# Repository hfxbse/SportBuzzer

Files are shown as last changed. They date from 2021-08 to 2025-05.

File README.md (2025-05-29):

# SportBuzzer
Wireless time measurement with two buzzer buttons, which also work as standalone.

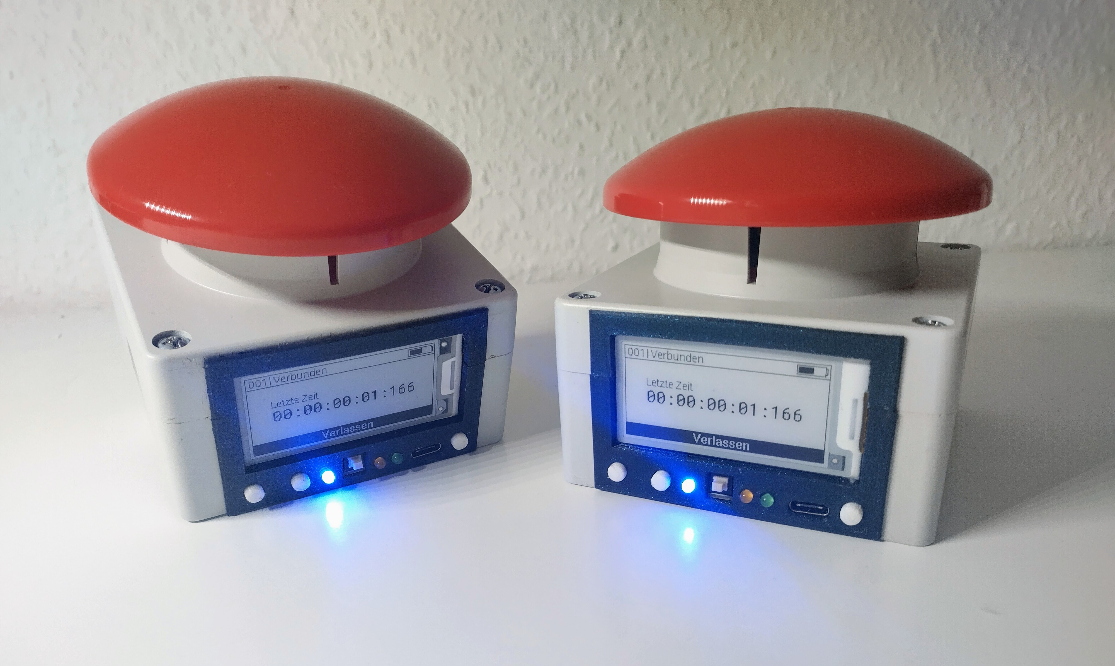
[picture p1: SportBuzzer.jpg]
Two SportBuzzer paired showing the same stopwatch time


## Usage
The GUI is controlled by the three buttons, called previous, next, and confirm. Generally speaking,
while navigating you use the previous button to go to the previous element, the next button to go to the
next element, and press the confirm button, to leave or enter a menu.

To change a value, you first need to navigate to the corresponding element. Then you press the confirm
button to start changing the value. Use the previous button to lower the value and use the next button
to increase it. When done editing the value, press the confirm button again to confirm your input.

While being in either the stopwatch or timer mode, pressing the buzzer button will start the time, and pressing
the buzzer button again will stop it. You can also cancel out by pressing the confirm button on the cancel element.
**After canceling no result is shown.**

When in the same wireless channel and same mode, pressing either of the buzzer buttons will stop the time.

Detailed information about the usage and limits can be found in the
[wiki](https://github.com/StuBITtv/SportBuzzer/wiki).

## Hardware

The design is based around the
[STM32L151CBU6 microcontroller](https://www.st.com/en/microcontrollers-microprocessors/stm32l151cb.html), which drives
an HC12 long-range wireless communication module and a
[Waveshare 2.13-inch black and white e-ink display](https://www.waveshare.com/2.13inch-e-Paper-HAT.htm). The board is
powered via a 1000mAh LiPo battery which is charged via USB-C. The data lines of the USB-C port are connected to the
MCU to provide expandability as well as an exposed additional UART connection on the PCB itself.

**Even though this project uses an HC12 module, I highly recommend replacing it.** Not only is it practically impossible
to find genuine modules which can deliver on the promised range, but more importantly, requires the used frequency of
433 MHz a license in large parts of the world. A promising alternative could be the
[RYLR998 LoRa module by REYAX](https://reyax.com/products/rylr998/). It operates in a license-free frequency range,
should achieve an even higher range, and has a small size. As it gets also controlled via AT commands like the HC12, the
changes required should be small.

JTAG and UART with buttons to select the boot mode are also exposed for uploading and debugging firmware.

The base of the casing is [this emergency off buzzer](https://bit.ly/3QsfA5K), all other parts are 3D-printed. One of
the wider sides is then cut open to place the front panel, which also secures the display. The other components are on a
mounting system, which is screwed to the bottom of the buzzer.

Due to the limited size of the chosen casing, a custom PCB is used. The schematics are created with
[EasyEDA](https://easyeda.com/), as their integration with [LCSC Electronics](https://www.lcsc.com/) made the design
and ordering process a lot simpler for me. As this is a cloud-based solution, you can open the
[schematics](https://oshwlab.com/StuBIT/sportbuzzer) directly.

Schematics

The production files are also directly included in this repository, nevertheless.

## Code

This project uses an [Arduino CMake toolchain](https://github.com/a9183756-gh/Arduino-CMake-Toolchain/),
but it is still possible to compile it within the [Arduino IDE](https://www.arduino.cc/en/Main/Software).
The only limitations are as follows:

* The `SportBuzzer.ino` file needs to be a file without any code in it to keep it compatible with both the
  Arduino IDE and the CMake toolchain. The only purpose of this file is to make it possible to open the
  project in the Arduino IDE.
* Due to the project size, it is necessary to split the project into multiple source files, which are organized in
  directories. The starting point of those directories needs to be `src/`, so the Arduino IDE picks it up. Still, the
  Arduino IDE won't show the directories and the containing files in the Editor.

The basic concepts of the code are as follows:

* Abstract the hardware as much as needed, so you are able to change it without needing to change stuff all over
  the code base.
* The main loop (`void loop()` to be more specific) handles background tasks. Background tasks include checking the
  battery level and the connection status. The main loop updates the foreground task (called `GUITask`) also,
  providing information about the hardware state, which it has already queried. To keep the displayed device state up
  to date, it may redraw the GUI arbitrarily.
* A GUITask handles everything related to its options, and time measurements. When done updating, it returns
  itself to keep alive, or a new GUITask to exit. After exiting, its state gets destroyed.
* To get accurate times without being limited by the refresh rate of the display, the buzzer is handled completely via
  interrupts. Implementations of GUITask rely on the time when the buzzer was pressed to detect if it was pressed.

Full documentation of the code can be found in the [wiki](https://github.com/StuBITtv/SportBuzzer/wiki).

Support from the Arduino IDE for the STM32-based microcontroller is added via the
[stm32duino](https://github.com/stm32duino/Arduino_Core_STM32) project. The correct settings for the custom PCB are
as follows:

* Board: "Generic STM32L1 series"
* Board part number: "GenericL151CBUx"

Remember to also choose the appropriate upload method.

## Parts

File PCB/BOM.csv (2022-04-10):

ID | Name | Designator | Footprint | Quantity | Manufacturer Part | Manufacturer | Supplier | Supplier Part
1 | 340kΩ | R11,R19,R21 | R0603 | 3 | 0603WAF3403T5E | UniOhm | LCSC | C23143
2 | SOFTWARE | BUZZER2 | BUZ-TH_BD12.0-P6.50-D0.6-FD | 1 | GMC1205YA-16R2048 | INGHAi | LCSC | C252915
3 | 22uF | C13 | C0603 | 1 | CL10A226MQ8NRNC | SAMSUNG | LCSC | C59461
4 | HC12 | H3 | HDR-TH_5P-P2.54-V-M | 1 | MTP125-1105S1 | MINTRON | LCSC | C358687
5 | DISPLAY | H4 | HDR-TH_8P-P2.54-V-M | 1 | Z-211-0811-0021-001 | Nextronics Engineering | LCSC | C190820
6 | BUZZER+ | P1 | HDR-TH_1P-P2.54-V-M | 1 | Header-Male-2.54_1x1 | ReliaPro | LCSC | C81276
7 | BUZZER- | P2 | HDR-TH_1P-P2.54-V-M | 1 | Header-Male-2.54_1x1 | ReliaPro | LCSC | C81276
8 | TYPE-C-31-M-14 | USBC1 | USB-C-SMD_12P-P0.50-H-F_TYPE-C-31-M-14 | 1 | TYPE-C-31-M-14 | Rectangular Connectors - Contacts | LCSC | C223907
9 | 200kΩ | R17,R20 | R0603 | 2 | 0603WAF2003T5E | UniOhm | LCSC | C25811
10 | 10uF | C9,C1,C2,C3,C4,C5,C6,C11 | C0402 | 8 | CL05A106MQ5NUNC | SAMSUNG | LCSC | C15525
11 | 1.5nF | C10 | C0402 | 1 | CL05B152KB5NNNC | SAMSUNG | LCSC | C23967
12 | 10uH | L1 | L0603 | 1 | SDFL1608S100KTF | Sunlord | LCSC | C1035
13 | 60.4kΩ | R10 | R0603 | 1 | 0603WAF6042T5E | UniOhm | LCSC | C23089
14 | 1.5kΩ | R18 | R0603 | 1 | 0603WAJ0152T5E | UniOhm | LCSC | C25989
15 | TX4401 | U3 | SOP-8_L4.9-W3.9-P1.27-LS6.0-BL-EP | 1 | TX4401 | XDS | LCSC | C448642
16 | JTAG | H1 | HDR-TH_4P-P2.54-H-M-W10.4 | 1 | 2.54-1*4P反弯排针 | BOOMELE(博穆精密) | LCSC | C91552
17 | 10K | R12,R16,R3,R7,R8,R9 | R0603 | 6 | 0603WAF1002T5E | UniOhm | LCSC | C25804
18 | 100 | R13,R4 | R0603 | 2 | 0603WAF1000T5E | UniOhm | LCSC | C22775
19 | 2.1K | R14 | R0603 | 1 | 0603WAF2101T5E | UniOhm | LCSC | C22902
20 | 25.5K | R15 | R0603 | 1 | 0603WAF2552T5E | UniOhm | LCSC | C22920
21 | Battery | H6 | CONN-TH_S2B-PH-K-S-LF-SN | 1 | S2B-PH-K-S(LF)(SN) | JST Sales America | LCSC | C173752
22 | 1TS001G-1600-1700 | BOOT0,RESET | SW-SMD_4P-L5.1-W5.1-P3.70-LS6.5-TL-2 | 2 | 1TS001G-1600-1700 | HYP | LCSC | C318802
23 | HARDWARE | BUZZER1 | BUZ-TH_BD9.0-P4.00-D0.6-FD | 1 | GMC0942YB-16R2700 | INGHAi | LCSC | C252926
24 | 10nF | C12,C7,C8 | C0402 | 3 | CL05B103KB5NNNC | SAMSUNG | LCSC | C15195
25 | ORANGE | CHRG | LED-TH_BD3.0-P2.54-FD | 1 | TJ-L3FYTXHAMCGLFLC0A-A5 | TOGIALED | LCSC | C330758
26 | BLUE | POWER | LED-TH_BD3.0-P2.54-FD | 1 | TJ-L3FYTGCBMCGSFLC6B-A5 | TOGIALED | LCSC | C330760
27 | TC-1109DE-C-D | CONF,NEXT,PREV | SW-TH_TC-1109DE-C-D | 3 | TC-1109DE-C-D | XKB Enterprise | LCSC | C400333
28 | B5819W_C8598 | D1,D2,D3 | SOD-123_L2.8-W1.8-LS3.7-RD | 3 | B5819W | CJ | LCSC | C8598
29 | GREEN | DONE | LED-TH_BD3.9-P2.54-L-RD | 1 | TJ-L3FYTGCGMCGLFLC2G-A5 | TOGIALED | LCSC | C331056
30 | UART1 | H2 | HDR-TH_2P-P2.54-H-M-W7.3 | 1 | 1125-1102G0R138C002 | Wcon | LCSC | C721441
31 | USART2 | H5 | HDR-TH_4P-P2.54-V-M-1 | 1 | MTP125-1104S1 | MINTRON | LCSC | C358686
32 | SI2301CDS-T1-GE3 | Q1,Q2,Q3,Q4 | SOT-23-3_L3.0-W1.7-P0.95-LS2.9-BR | 4 | SI2301CDS-T1-GE3 | VISHAY | LCSC | C10487
33 | 2K | R1 | R0603 | 1 | 0603WAF2001T5E | UniOhm | LCSC | C22975
34 | 1K | R2 | R0603 | 1 | 0603WAF1001T5E | UniOhm | LCSC | C21190
35 | 5.1K | R5,R6 | R0603 | 2 | 0603WAF5101T5E | UniOhm | LCSC | C23186
36 | XKB5858-Z-C | SW1 | SW-TH_XKB5858-Z-C | 1 | XKB5858-Z-C | XKB Enterprise | LCSC | C318865
37 | LP4074B5F | U1 | TSOT-23-5_L2.9-W1.6-P0.95-LS2.8-BL | 1 | LP4074B5F | LOWPOWER | LCSC | C517037
38 | XB3301AJ | U2 | SOT-23-3_L2.9-W1.6-P1.90-LS2.8-BR | 1 | XB3301AJ | xysemi(赛芯微) | LCSC | C2760004
39 | STM32L151CBU6 | U4 | UFQFPN-48_L7.0-W7.0-P0.50-BL-EP | 1 | STM32L151CBU6 | STMicroelectronics | LCSC | C465975
40 | NE555D_C596355 | U5 | SOP-8_L4.9-W3.9-P1.27-LS6.0-BL | 1 | NE555D | HTC Korea TAEJIN Tech | LCSC | C596355

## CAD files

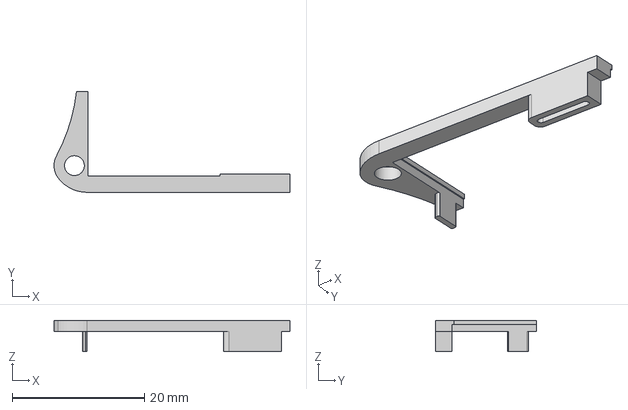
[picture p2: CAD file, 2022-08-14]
casing/STEP/antenna mount.step
35.7 x 15.2 x 4.70 mm

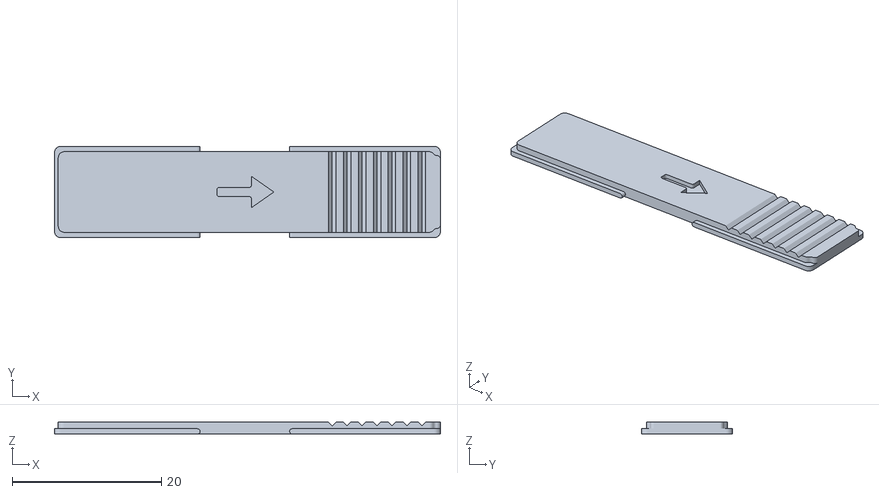
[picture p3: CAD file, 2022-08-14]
casing/STL/battery enclosure lit.stl
51.7 x 12.2 x 1.60

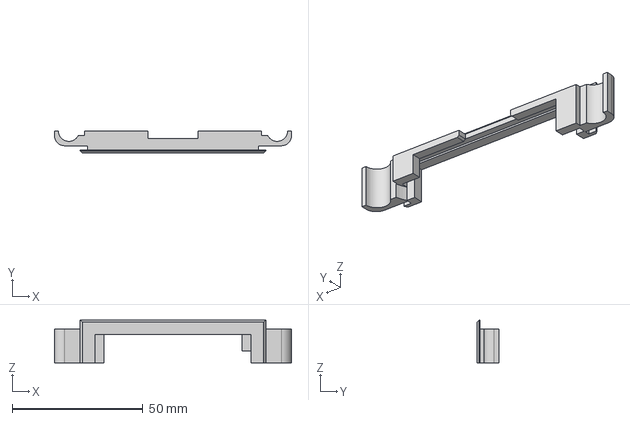
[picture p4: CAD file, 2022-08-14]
casing/STEP/panelling top.step
90.8 x 8.50 x 16.4 mm

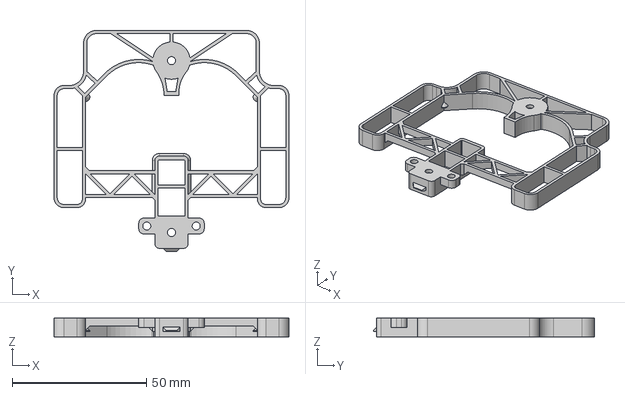
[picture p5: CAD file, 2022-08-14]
casing/STEP/pcb mount.step
87.5 x 82.3 x 7.00 mm

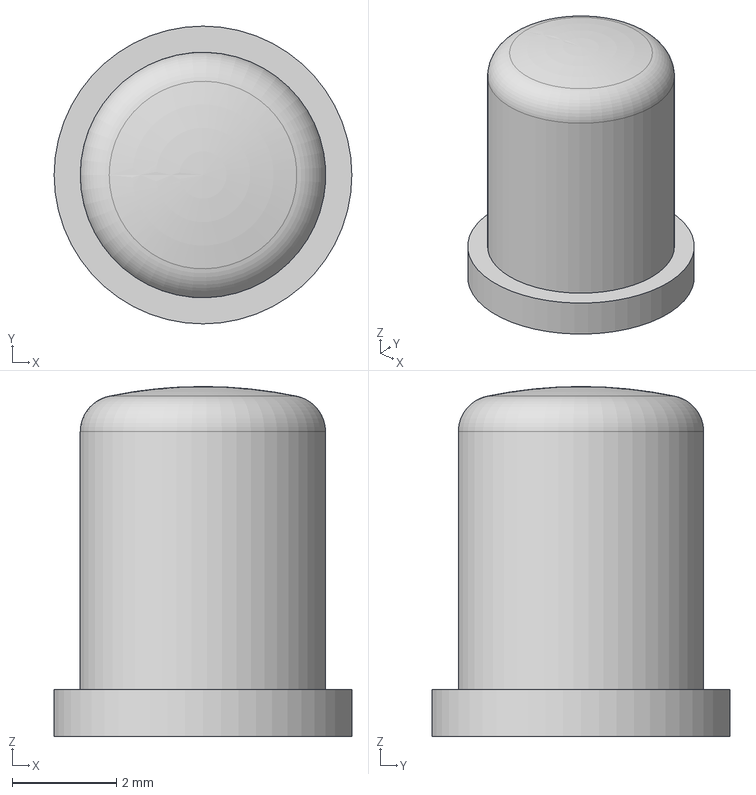
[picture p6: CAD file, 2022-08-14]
casing/STEP/button.step
5.70 x 5.70 x 6.70 mm

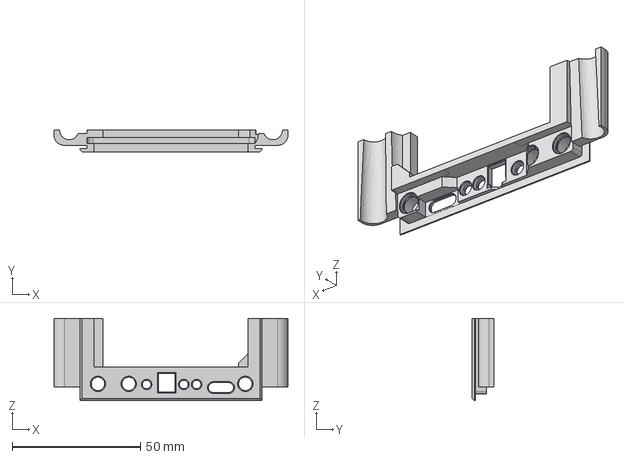
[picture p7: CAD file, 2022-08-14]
casing/STEP/panelling lower.step
91.3 x 8.40 x 32.0 mm

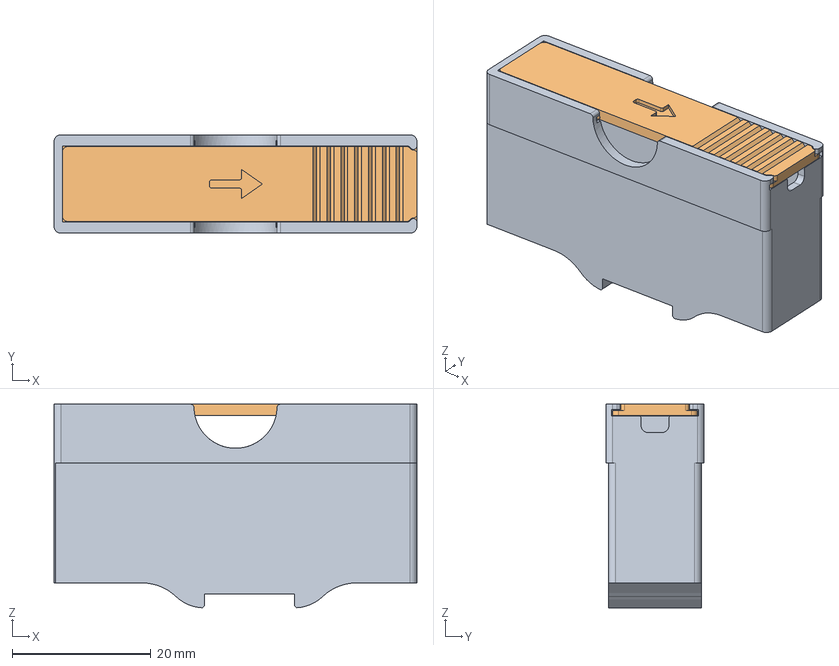
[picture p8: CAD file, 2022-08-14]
casing/STEP/battery enclosure.step
52.4 x 14.2 x 29.4 mm

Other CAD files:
casing/STL/antenna mount.stl
casing/STL/battery enclosure.stl
casing/STL/button.stl
casing/STL/panelling lower.stl
casing/STL/panelling top.stl
casing/STL/pcb mount.stl
casing/antenna mount.f3d
casing/batterie enclosure.f3d
casing/button.f3d
casing/panelling lower.f3d
casing/panelling top.f3d
casing/pcb mount.f3d

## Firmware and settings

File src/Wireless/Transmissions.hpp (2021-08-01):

//
// Created by stubit on 4/25/20.
//

#ifndef SPORTBUZZER_TRANSMISSIONS_HPP
#define SPORTBUZZER_TRANSMISSIONS_HPP


#include <Arduino.h>
#include "../HardwareInterfaces/HC12.hpp"

enum Signal {
    undefined = 0,
    ping = 1,
    pong = 2,
    cancel_stopwatch = 3,
    cancel_timer = 4,
    duration_stopwatch = 5,
    duration_timer = 6,
    limit = 7,
    stopwatch = 8,
    timer = 9,
};

enum TransmissionStatus {
    unfinished = 1,
    finished = 0,
    timeout = -1,
};

class Transmissions {
public:
    explicit Transmissions(HC12 &module);

    void poll();

    bool sendPing(unsigned long timeout);

    TransmissionStatus getPingStatus() const;

    unsigned long getPingResponseTime();

    unsigned long getPingTime() const;

    unsigned long popReceivedPing();

    void sendPingResponse() const;

    void waitOnPing();

    void sendStopwatchSignal() const;

    unsigned long getStopwatchSignalTime() const;

    void sendTimerSignal() const;

    unsigned long getTimerSignalTime() const;

    unsigned long transmissionTimeout = 5000;

    TransmissionStatus getDurationTransmissionStatus() const;

    unsigned long getTransmittedDuration() const;

    void sendDuration(unsigned long duration, bool stopwatch) const;

    byte getDurationNumber() const;

    Signal getDurationSignal() const;

    TransmissionStatus getLimitTransmissionStatus() const;

    long getTransmittedLimit() const;

    void sendLimit(long limit) const;

    byte getLimitNumber() const;

    void sendCancelSignal(bool stopwatch) const;

    byte getCancelNumber() const;

    Signal getCancelSignal() const;

private:
    // related to module
    HC12 &module;

    // related to ping signals
    unsigned long pingStart = 0, pingResponseTime = 0, receivedPingCount = 0, pingTimeout = 0;
    TransmissionStatus pingStatus = finished;

    // related to stopwatch signal
    unsigned long stopwatchTime = 0;

    // related to timer signal
    unsigned long timerTime = 0;

    // related to cancel signal
    byte receivedCancelCount = 0;
    Signal cancelSignal = undefined;

    // related to duration transmission
    TransmissionStatus durationTransmissionStatus = finished;
    byte transmittedDurationBytes = 0, receivedDurationCount = 0;
    unsigned long transmittedDuration = 0, durationTransmissionStart = 0;
    Signal timeSignal = Signal::undefined;

    // related to limit transmission
    TransmissionStatus limitTransmissionStatus = finished;
    byte transmittedLimitBytes = 0, receivedLimitCount = 0;
    long transmittedLimit = 0;
    unsigned long limitTransmissionStart = 0;

    template<typename T>
    T writeData(T value, byte &transmittedByteCount, TransmissionStatus &status, byte &transmissionNumber);
};


#endif //SPORTBUZZER_TRANSMISSIONS_HPP

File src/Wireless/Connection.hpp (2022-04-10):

//
// Created by stubit on 7/15/20.
//

#ifndef SPORTBUZZER_CONNECTION_HPP
#define SPORTBUZZER_CONNECTION_HPP

#include "Transmissions.hpp"

#ifdef __AVR
#define HC12_TX_PIN 10
#define HC12_RX_PIN 11
#define HC12_SET_PIN 9
#else
#define HC12_TX_PIN PB10
#define HC12_RX_PIN PB11
#define HC12_SET_PIN PB1
#endif

#define TIMEOUT 2000

namespace Connection {
    void setup();

    size_t handlePingSignals(Transmissions &transmissions);

    extern HC12 hc12;

    void updateConnectionStatus(TransmissionStatus status, std::function<void(bool connected)> draw);
}

#endif //SPORTBUZZER_CONNECTION_HPP

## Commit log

2020-04-12 setup arduino cmake toolchain
2020-04-13 add dBm info to transmission power modes
2020-04-15 make Arduino IDE compatible
2020-04-25 move board option to cmake variables
2020-06-19 add buttons
2020-07-15 fix sending command before entering AT mode
    [HC12.cpp]
2020-07-16 create src folder for arduino ide compatibility
2020-07-17 add timer
2020-07-17 add cancel synchronization, ignore time limit changes when timer is running
2020-07-17 fix limit getting falsely overridden
    [Timer.hpp, Transmissions.hpp]
2020-07-20 change schematics section name
2020-07-22 fix time limit overflow errors
    [Timer.hpp, Transmissions.hpp]
2020-07-22 clarified buzzer being a buzzer button in readme
2021-08-01 add stm32duino compatability
2021-08-05 draw timer on display
2022-02-04 add PCB design
    [BOM.csv]
2022-04-08 update PCB to reflect applied fixes
2022-04-08 fix serial for custom PCB
2022-04-10 fetch battery level
2022-04-10 bumped PCB version to v1.2-6
    [BOM.csv]
2022-04-10 replaced battery percentage with indicator
    [StatusBar.hpp]
2022-04-10 hide battery indicator when power over usb
2022-04-10 reduce battery level precision to limit display refreshes
2022-08-12 debounce buzzer via interrupts
2022-08-14 add casing CAD files
    [antenna mount.f3d, antenna mount.step, antenna mount.stl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]
